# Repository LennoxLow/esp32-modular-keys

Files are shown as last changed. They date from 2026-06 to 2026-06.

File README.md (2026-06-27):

# ESP32 MODULAR HOTKEY SYSTEM 🔘✨
*"A physical button that can trigger anything. The first thing I used it for was generating meme compilations."*

---

## 🎬 As Seen In
This project appeared in my YouTube video:
I automated making meme compilations so I never have to watch Reddit again (https://www.youtube.com/watch?v=LXZIZYsod2A) 

And yes — it's also on Instructables 👀
[[Happy Modular HotKeys](https://www.instructables.com/Happy-Modular-HotKeys-ESP32/)]

---

## ⚠️ What Is This?

Running a script from a terminal works fine.

But I wanted a physical button. Something that felt like I was actually doing something rather than typing `python main.py` and pressing enter like some kind of person who uses a computer normally.

So I built one. And then it got a bit out of hand.

Each module is an ESP32 with a button, an OLED display, and a 20-frame animation that plays when a trigger fires. The interesting part is what happens when you connect more than one — they negotiate master and slave roles automatically with no configuration, communicate over a serial bus, and broadcast triggers over WiFi UDP so everything connected hears every press.

Press any button on any module. Everything reacts.

---

## 🧠 Features

- Auto master/slave role negotiation via shared flag pin — no configuration needed
- Serial bus communication between modules (daisy-chainable)
- WiFi UDP broadcast so triggers reach anything on the network
- Automatic master promotion if master module is powered off
- GUID-based device identity — every module knows who sent what
- 20-frame OLED animation stored in PROGMEM — no SD card needed
- 25ms debounce on button input
- Periodic slave keepalive announcements
- Serial listener on PC side triggers any script on button press
- Modular — add as many buttons as you want

---

## 🧰 Parts List

| Part | Notes |
|---|---|
| ESP32 (any variant) | One per module |
| Tactile push button | Wired to GPIO6 and GND |
| 0.66 Inch OLED  | I²C, address 0x3C |
| Jumper wires | For the bus between modules |
| USB cable | Flashing and power |
| 3D printed enclosure | Optional but satisfying |
| Arduino IDE | Where bugs are born |

---

## 🗺️ GPIO Map

| Pin | Function |
|-----|---|
| GPIO 4 | I²C SDA → OLED |
| GPIO 5 | I²C SCL → OLED |
| GPIO 6 | Button (INPUT_PULLUP — wire to GND) |
| GPIO 7 | Master/slave flag pin |
| GPIO 20 | Serial RX (swapped on slave) |
| GPIO 21 | Serial TX (swapped on slave) |

**Button wiring:** One leg to GPIO6, other leg to GND. The internal pullup holds the pin HIGH. Press pulls it LOW — that's your trigger.

**Flag pin wiring:** Connect GPIO7 on all modules together with a single shared wire. This is how they negotiate roles on boot.

**Serial bus wiring:** TX of one module to RX of the next. Daisy chain as many as you want.

---

## 🧠 How the Master/Slave Negotiation Works

On boot, every module checks the shared flag pin (GPIO7):

- **Pin is LOW** — nobody has claimed master yet. This module sets the pin HIGH, declares itself master, and connects to WiFi.
- **Pin is HIGH** — a master already exists. This module becomes a slave, announces itself over the serial bus, and waits.

Power off the master mid-session — the slave detects the flag pin going LOW, waits 2 seconds to confirm it's not a glitch, then promotes itself to master.

No configuration. No pre-assignment. They just figure it out.

---

## 📡 Trigger Flow

**Master button pressed:**
```
Master button → broadcastMessage() → WiFi UDP + Serial bus → all modules react
```

**Slave button pressed:**
```
Slave button → busSend() to master → master forwards via broadcastMessage() → all modules react
```

Every trigger message includes the sending module's GUID so you always know which button fired.

---

## 🖥️ PC Serial Listener

A Python script on the PC side watches the serial port. When it receives a `TRIGGER` message from the master module it fires whatever script you point it at.

```python
import serial
import subprocess

ser = serial.Serial('COM3', 115200)  # Change to your port

while True:
    if ser.in_waiting:
        line = ser.readline().decode('utf-8').strip()
        if 'TRIGGER' in line:
            subprocess.call(['python', 'main.py'])
```

Change `COM3` to your actual port. Change `main.py` to whatever you want the button to run. That's the entire bridge between hardware and software.

---

## 🚀 Setup

**1. Install Arduino IDE**

Download from arduino.cc.

**2. Add ESP32 board support**

In Arduino IDE preferences, add this to Additional Board Manager URLs:
```
https://raw.githubusercontent.com/espressif/arduino-esp32/gh-pages/package_esp32_index.json
```

Then install `esp32` via Board Manager.

**3. Install libraries**

In Library Manager, install:
- `Adafruit SSD1306`
- `Adafruit GFX`

**4. Configure WiFi credentials**

In the firmware, find and update:
```cpp
const char* ssid = "YOUR_WIFI_SSID";
const char* password = "YOUR_WIFI_PASSWORD";
```

**5. Flash each module**

- Connect via USB
- Select your ESP32 board
- Upload the sketch
- Repeat for each module

**6. Wire the modules together**

- Connect all GPIO7 pins together (flag bus)
- Connect TX/RX in daisy chain for serial bus
- Power all modules

**7. Run the serial listener**

```bash
python listener.py
```

**8. Press the button**

---

## ✨ The OLED Animation

When any trigger fires, all connected OLED screens play a 20-frame bounce animation.

The animation frames are stored as raw bitmaps in PROGMEM — meaning they live in flash memory on the microcontroller itself. No SD card, no external storage, no loading time. It just plays.

Each frame is 46×46 pixels. The animation plays forward then reverses in a loop until the next trigger.

---

## 🛠️ Troubleshooting

**OLED is blank**
- Check I²C wiring — SDA to GPIO4, SCL to GPIO5
- Confirm I²C address is `0x3C`
- Check common ground between ESP32 and OLED

**Modules not negotiating roles correctly**
- Make sure GPIO7 is connected between all modules with a shared wire
- Check that GPIO7 is not connected to anything else
- Power modules on one at a time to observe negotiation

**Slave not receiving triggers from master**
- Check TX/RX wiring — master TX to slave TX pin (firmware swaps it internally)
- Confirm both modules share a common ground
- Check baud rate is 115200 on both

**WiFi not connecting**
- Check SSID and password in firmware
- Master only connects to WiFi — slaves use serial bus only
- If WiFi fails, the master falls back to serial bus automatically

**Serial listener not receiving triggers**
- Check COM port — use Device Manager on Windows to find it
- Confirm baud rate is 115200
- Make sure the master module is connected to the PC, not a slave

**Button not triggering**
- Check wiring: one leg to GPIO6, other leg to GND
- Confirm `INPUT_PULLUP` is set in firmware
- Trigger fires on LOW — pressing should pull the pin to GND

---

## 🚀 Future Shenanigans

- Different trigger types per button (long press, double press)
- Battery power + wireless only mode
- Per-module custom animations
- Web interface for trigger configuration
- More modules obviously

---

## 🔗 Companion Project

The button was built to trigger this:
👉 [LennoxLow/Automatic-Meme-Compilation-Creator]((https://github.com/LennoxLow/Automatic-Meme-Compilation-Creator))

But it can trigger anything that runs from a command line.

I haven't decided what to make it do next.

---

## 🖤 License

Do whatever.
Attribute me if you feel polite.

-readme was generated, instructables is a good source for any additional information-

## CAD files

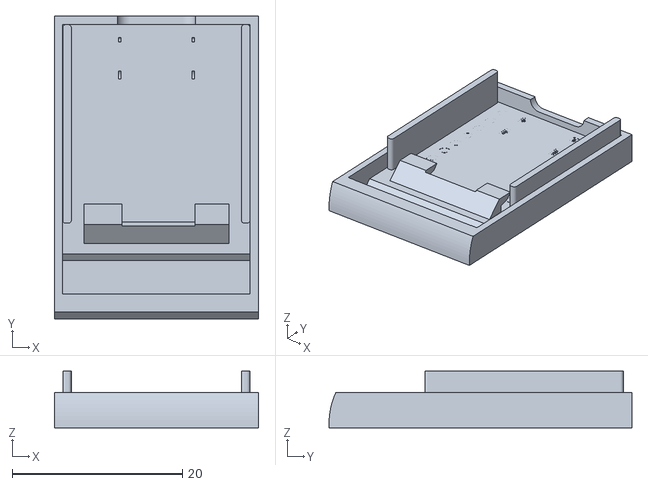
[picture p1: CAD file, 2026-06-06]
Quickkeys- bottom.stl
24.0 x 35.6 x 6.66

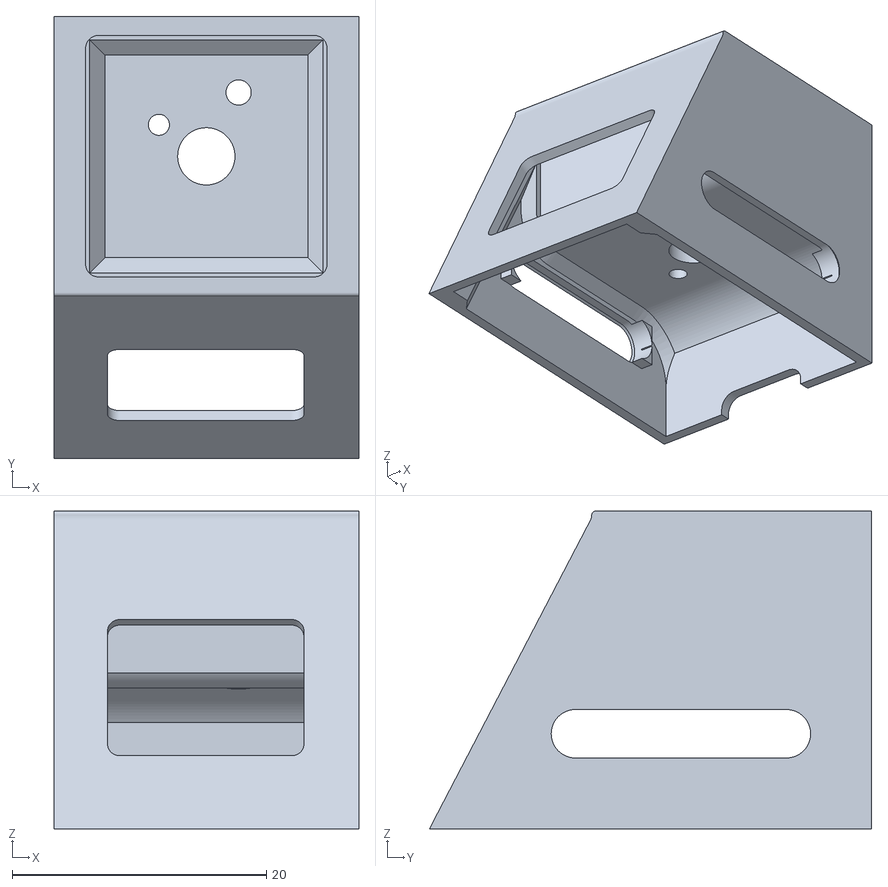
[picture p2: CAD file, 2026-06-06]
Quickkeys-newtop.stl
24.0 x 34.8 x 25.0

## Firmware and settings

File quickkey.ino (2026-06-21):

#include <Wire.h>
#include <Adafruit_GFX.h>
#include <Adafruit_SSD1306.h>
#include <WiFi.h>
#include <WiFiUdp.h>
#include <Preferences.h>

// === Wi-Fi config ===
const char* ssid = "YOUR_WIFI_SSID";
const char* password = "YOUR_WIFI_PASSWORD";
const int udpPort = 5555;
WiFiUDP udp;
IPAddress broadcastIP;
bool wifiActive = false;

// === Screen config ===
#define SCREEN_WIDTH 128
#define SCREEN_HEIGHT 64
#define OLED_ADDR 0x3C
Adafruit_SSD1306 display(SCREEN_WIDTH, SCREEN_HEIGHT, &Wire, -1);

// === Pins ===
#define PIN_BUTTON 6
#define PIN_FLAG   7
#define PIN_SDA    4
#define PIN_SCL    5
#define PIN_RX     20
#define PIN_TX     21

// === Debounce ===
unsigned long lastDebounceTime = 0;
unsigned long debounceDelay = 25;
bool buttonState = HIGH;
bool lastButtonReading = HIGH;

// === Bus Communication ===
#define BAUD 115200
bool isMaster = false;
String guid;
String unitName;
Preferences prefs;
unsigned long lastSlaveAnnounce = 0;
unsigned long slaveAnnounceInterval = 5000;

// === Animation state machine ===
enum AnimState { IDLE, TRIGGERED, COMBO };
AnimState animState = IDLE;
unsigned long lastFrameTime = 0;
unsigned long stateStartTime = 0;
int currentFrame = 0;
bool animationReverse = false;
String overlayText = "";
const int IDLE_FRAME_DELAY      = 120;
const int TRIGGERED_FRAME_DELAY = 55;
const int COMBO_FRAME_DELAY     = 35;
const unsigned long TRIGGERED_DURATION = 1500;
const unsigned long COMBO_DURATION     = 2500;

// === Long press ===
unsigned long buttonPressedAt = 0;
bool longPressFired = false;
const unsigned long LONG_PRESS_MS = 800;

// === Slave tracking (master only) ===
#define MAX_SLAVES 8
struct SlaveInfo { String guid; String name; unsigned long lastSeen; };
SlaveInfo slaves[MAX_SLAVES];
int slaveCount = 0;
const unsigned long SLAVE_TIMEOUT = 15000;

// === Combo detection (master only) ===
#define MAX_COMBO_TRACK 8
struct RecentTrigger { String name; unsigned long time; };
RecentTrigger recentTriggers[MAX_COMBO_TRACK];
int recentTriggerCount = 0;
const unsigned long COMBO_WINDOW_MS = 600;

// === Sprite frames (45x45px) ===
// ========================================
// ANIMATION FRAMES - Dance (46x46px, 20 frames)
// ========================================
// 'frame_00_delay-0', 46x46px
const unsigned char frame_00 [] PROGMEM = {
	0x00, 0x00, 0x00, 0x00, 0x00, 0x00, 0x00, 0x00, 0x00, 0x00, 0x00, 0x00, 0x00, 0x00, 0x00, 0x00, 
	0x00, 0x00, 0x00, 0x00, 0x00, 0x00, 0x00, 0x00, 0x00, 0x00, 0x00, 0x00, 0x00, 0x00, 0x00, 0x00, 
	0x07, 0xfc, 0x00, 0x00, 0x00, 0x00, 0x3f, 0xff, 0x80, 0x00, 0x00, 0x01, 0xff, 0xff, 0xe0, 0x00, 
	0x00, 0x07, 0xff, 0xff, 0xf8, 0x00, 0x00, 0x0f, 0xff, 0xff, 0xfc, 0x00, 0x00, 0x1f, 0xff, 0xff, 
	0xfe, 0x00, 0x00, 0x3f, 0xff, 0xff, 0xff, 0x00, 0x00, 0x7f, 0xff, 0xff, 0x0f, 0x00, 0x00, 0xff, 
	0xff, 0xfe, 0x0f, 0x80, 0x01, 0xff, 0xe3, 0xfe, 0x07, 0x80, 0x01, 0xff, 0xe1, 0xff, 0x07, 0xc0, 
	0x03, 0xff, 0xc0, 0xff, 0x07, 0xc0, 0x03, 0xff, 0xc0, 0xff, 0xdf, 0xe0, 0x07, 0xff, 0xe0, 0xff, 
	0xff, 0xe0, 0x07, 0xff, 0xe1, 0xff, 0xff, 0xe0, 0x0f, 0xff, 0xff, 0xff, 0xe7, 0xe0, 0x0f, 0xff, 
	0xff, 0xff, 0x87, 0xf0, 0x0f, 0xff, 0xfd, 0xfe, 0x1f, 0xf0, 0x1f, 0xff, 0xfc, 0x00, 0x7f, 0xf0, 
	0x1f, 0xff, 0xfe, 0x01, 0xff, 0xf0, 0x1f, 0xff, 0xff, 0xff, 0xff, 0xf0, 0x3f, 0xff, 0xff, 0xff, 
	0xff, 0xf0, 0x3f, 0xff, 0xff, 0xff, 0xff, 0xf0, 0x3f, 0xff, 0xff, 0xff, 0xff, 0xf0, 0x3f, 0xff, 
	0xff, 0xff, 0xff, 0xf0, 0x3f, 0xff, 0xff, 0xff, 0xff, 0xf0, 0x3f, 0xff, 0xff, 0xff, 0xff, 0xf0, 
	0x3f, 0xff, 0xff, 0xff, 0xff, 0xf0, 0x3f, 0xff, 0xff, 0xff, 0xff, 0xf0, 0x3f, 0xff, 0xff, 0xff, 
	0xff, 0xf0, 0x1f, 0xff, 0xff, 0xff, 0xff, 0xe0, 0x0f, 0xff, 0xff, 0xff, 0xff, 0xc0, 0x03, 0xff, 
	0xff, 0xff, 0xff, 0x00, 0x01, 0xff, 0xff, 0xff, 0xfe, 0x00, 0x00, 0x1f, 0xff, 0xff, 0xe0, 0x00, 
	0x00, 0x01, 0xff, 0xfe, 0x00, 0x00, 0x00, 0x00, 0x00, 0x00, 0x00, 0x00, 0x00, 0x00, 0x00, 0x00, 
	0x00, 0x00, 0x00, 0x00, 0x00, 0x00, 0x00, 0x00, 0x00, 0x00, 0x00, 0x00, 0x00, 0x00, 0x00, 0x00, 
	0x00, 0x00, 0x00, 0x00
};
// 'frame_01_delay-0', 46x46px
const unsigned char frame_01 [] PROGMEM = {
	0x00, 0x00, 0x00, 0x00, 0x00, 0x00, 0x00, 0x00, 0x00, 0x00, 0x00, 0x00, 0x00, 0x00, 0x00, 0x00, 
	0x00, 0x00, 0x00, 0x00, 0x00, 0x00, 0x00, 0x00, 0x00, 0x00, 0x00, 0x00, 0x00, 0x00, 0x00, 0x00, 
	0x3f, 0xf0, 0x00, 0x00, 0x00, 0x01, 0xff, 0xfe, 0x00, 0x00, 0x00, 0x0f, 0xff, 0xff, 0xc0, 0x00, 
	0x00, 0x1f, 0xff, 0xff, 0xe0, 0x00, 0x00, 0x3f, 0xff, 0xff, 0xf0, 0x00, 0x00, 0x7f, 0xff, 0xff, 
	0xf8, 0x00, 0x00, 0xff, 0xff, 0xff, 0xfc, 0x00, 0x01, 0xff, 0xff, 0xff, 0xfe, 0x00, 0x01, 0xff, 
	0xff, 0xfc, 0x7e, 0x00, 0x03, 0xff, 0xff, 0xf8, 0x3f, 0x00, 0x07, 0xff, 0xcf, 0xf8, 0x1f, 0x80, 
	0x07, 0xff, 0x87, 0xf8, 0x1f, 0x80, 0x07, 0xff, 0x07, 0xfc, 0x1f, 0xc0, 0x0f, 0xff, 0x03, 0xfc, 
	0x3f, 0xc0, 0x0f, 0xff, 0x03, 0xff, 0xff, 0xc0, 0x0f, 0xff, 0x87, 0xff, 0xff, 0xc0, 0x1f, 0xff, 
	0xcf, 0xff, 0xff, 0xe0, 0x1f, 0xff, 0xff, 0xff, 0x1f, 0xe0, 0x1f, 0xff, 0xff, 0xfc, 0x3f, 0xe0, 
	0x3f, 0xff, 0xe0, 0x00, 0xff, 0xf0, 0x3f, 0xff, 0xf0, 0x07, 0xff, 0xf0, 0x3f, 0xff, 0xff, 0xff, 
	0xff, 0xf0, 0x3f, 0xff, 0xff, 0xff, 0xff, 0xf0, 0x3f, 0xff, 0xff, 0xff, 0xff, 0xf0, 0x3f, 0xff, 
	0xff, 0xff, 0xff, 0xf0, 0x3f, 0xff, 0xff, 0xff, 0xff, 0xf0, 0x3f, 0xff, 0xff, 0xff, 0xff, 0xf0, 
	0x3f, 0xff, 0xff, 0xff, 0xff, 0xf0, 0x3f, 0xff, 0xff, 0xff, 0xff, 0xf0, 0x3f, 0xff, 0xff, 0xff, 
	0xff, 0xf0, 0x1f, 0xff, 0xff, 0xff, 0xff, 0xe0, 0x0f, 0xff, 0xff, 0xff, 0xff, 0xc0, 0x03, 0xff, 
	0xff, 0xff, 0xff, 0x00, 0x01, 0xff, 0xff, 0xff, 0xfe, 0x00, 0x00, 0x1f, 0xff, 0xff, 0xe0, 0x00, 
	0x00, 0x01, 0xff, 0xfe, 0x00, 0x00, 0x00, 0x00, 0x00, 0x00, 0x00, 0x00, 0x00, 0x00, 0x00, 0x00, 
	0x00, 0x00, 0x00, 0x00, 0x00, 0x00, 0x00, 0x00, 0x00, 0x00, 0x00, 0x00, 0x00, 0x00, 0x00, 0x00, 
	0x00, 0x00, 0x00, 0x00
};
// 'frame_02_delay-0', 46x46px
const unsigned char frame_02 [] PROGMEM = {
	0x00, 0x00, 0x00, 0x00, 0x00, 0x00, 0x00, 0x00, 0x00, 0x00, 0x00, 0x00, 0x00, 0x00, 0x00, 0x00, 
	0x00, 0x00, 0x00, 0x00, 0x00, 0x00, 0x00, 0x00, 0x00, 0x00, 0x00, 0x00, 0x00, 0x00, 0x00, 0x00, 
	0x7f, 0xc0, 0x00, 0x00, 0x00, 0x03, 0xff, 0xf8, 0x00, 0x00, 0x00, 0x0f, 0xff, 0xff, 0x00, 0x00, 
	0x00, 0x3f, 0xff, 0xff, 0xc0, 0x00, 0x00, 0x7f, 0xff, 0xff, 0xe0, 0x00, 0x00, 0xff, 0xff, 0xff, 
	0xf0, 0x00, 0x01, 0xff, 0xff, 0xff, 0xf8, 0x00, 0x01, 0xfe, 0x7f, 0xf3, 0xfc, 0x00, 0x03, 0xfc, 
	0x3f, 0xe1, 0xfc, 0x00, 0x03, 0xfc, 0x1f, 0xe1, 0xfe, 0x00, 0x07, 0xf8, 0x1f, 0xc0, 0xff, 0x00, 
	0x07, 0xfc, 0x1f, 0xe1, 0xff, 0x00, 0x0f, 0xfc, 0x3f, 0xe1, 0xff, 0x80, 0x0f, 0xfe, 0x7f, 0xff, 
	0xff, 0x80, 0x0f, 0xff, 0xff, 0xff, 0xff, 0xc0, 0x1f, 0xff, 0xff, 0xff, 0xff, 0xc0, 0x1f, 0xfe, 
	0x7f, 0xfb, 0xff, 0xc0, 0x1f, 0xfe, 0x0f, 0x83, 0xff, 0xe0, 0x1f, 0xff, 0x80, 0x0f, 0xff, 0xe0, 
	0x3f, 0xff, 0xf0, 0x7f, 0xff, 0xe0, 0x3f, 0xff, 0xff, 0xff, 0xff, 0xe0, 0x3f, 0xff, 0xff, 0xff, 
	0xff, 0xf0, 0x3f, 0xff, 0xff, 0xff, 0xff, 0xf0, 0x3f, 0xff, 0xff, 0xff, 0xff, 0xf0, 0x3f, 0xff, 
	0xff, 0xff, 0xff, 0xf0, 0x3f, 0xff, 0xff, 0xff, 0xff, 0xf0, 0x3f, 0xff, 0xff, 0xff, 0xff, 0xf0, 
	0x3f, 0xff, 0xff, 0xff, 0xff, 0xf0, 0x3f, 0xff, 0xff, 0xff, 0xff, 0xf0, 0x3f, 0xff, 0xff, 0xff, 
	0xff, 0xf0, 0x1f, 0xff, 0xff, 0xff, 0xff, 0xe0, 0x0f, 0xff, 0xff, 0xff, 0xff, 0xc0, 0x03, 0xff, 
	0xff, 0xff, 0xff, 0x00, 0x01, 0xff, 0xff, 0xff, 0xfe, 0x00, 0x00, 0x1f, 0xff, 0xff, 0xe0, 0x00, 
	0x00, 0x01, 0xff, 0xfe, 0x00, 0x00, 0x00, 0x00, 0x00, 0x00, 0x00, 0x00, 0x00, 0x00, 0x00, 0x00, 
	0x00, 0x00, 0x00, 0x00, 0x00, 0x00, 0x00, 0x00, 0x00, 0x00, 0x00, 0x00, 0x00, 0x00, 0x00, 0x00, 
	0x00, 0x00, 0x00, 0x00
};
// 'frame_03_delay-0', 46x46px
const unsigned char frame_03 [] PROGMEM = {
	0x00, 0x00, 0x00, 0x00, 0x00, 0x00, 0x00, 0x00, 0x00, 0x00, 0x00, 0x00, 0x00, 0x00, 0x00, 0x00, 
	0x00, 0x00, 0x00, 0x00, 0x00, 0x00, 0x00, 0x00, 0x00, 0x00, 0x00, 0x00, 0x00, 0x00, 0x00, 0x00, 
	0x00, 0x00, 0x00, 0x00, 0x00, 0x00, 0x7f, 0x80, 0x00, 0x00, 0x00, 0x0f, 0xff, 0xf8, 0x00, 0x00, 
	0x00, 0x3f, 0xff, 0xfe, 0x00, 0x00, 0x00, 0x7f, 0xff, 0xff, 0x80, 0x00, 0x00, 0xff, 0xff, 0xff, 
	0xc0, 0x00, 0x01, 0xff, 0xff, 0xff, 0xe0, 0x00, 0x03, 0xff, 0xff, 0xcf, 0xf0, 0x00, 0x07, 0xff, 
	0xff, 0x83, 0xf8, 0x00, 0x07, 0xf9, 0xff, 0x83, 0xfc, 0x00, 0x0f, 0xf0, 0x7f, 0x83, 0xfe, 0x00, 
	0x0f, 0xf0, 0x7f, 0x83, 0xfe, 0x00, 0x0f, 0xf0, 0x7f, 0xc7, 0xff, 0x00, 0x1f, 0xf0, 0x7f, 0xff, 
	0xff, 0x80, 0x1f, 0xf0, 0x7f, 0xff, 0xff, 0x80, 0x1f, 0xfd, 0xff, 0xff, 0xff, 0xc0, 0x3f, 0xff, 
	0xff, 0xe3, 0xff, 0xc0, 0x3f, 0xff, 0xff, 0x87, 0xff, 0xc0, 0x3f, 0xfe, 0x00, 0x1f, 0xff, 0xe0, 
	0x3f, 0xff, 0x00, 0x7f, 0xff, 0xe0, 0x3f, 0xff, 0xff, 0xff, 0xff, 0xe0, 0x3f, 0xff, 0xff, 0xff, 
	0xff, 0xf0, 0x3f, 0xff, 0xff, 0xff, 0xff, 0xf0, 0x3f, 0xff, 0xff, 0xff, 0xff, 0xf0, 0x3f, 0xff, 
	0xff, 0xff, 0xff, 0xf0, 0x3f, 0xff, 0xff, 0xff, 0xff, 0xf0, 0x3f, 0xff, 0xff, 0xff, 0xff, 0xf0, 
	0x3f, 0xff, 0xff, 0xff, 0xff, 0xf0, 0x3f, 0xff, 0xff, 0xff, 0xff, 0xf0, 0x3f, 0xff, 0xff, 0xff, 
	0xff, 0xf0, 0x1f, 0xff, 0xff, 0xff, 0xff, 0xe0, 0x0f, 0xff, 0xff, 0xff, 0xff, 0xc0, 0x03, 0xff, 
	0xff, 0xff, 0xff, 0x00, 0x01, 0xff, 0xff, 0xff, 0xfe, 0x00, 0x00, 0x1f, 0xff, 0xff, 0xe0, 0x00, 
	0x00, 0x01, 0xff, 0xfe, 0x00, 0x00, 0x00, 0x00, 0x00, 0x00, 0x00, 0x00, 0x00, 0x00, 0x00, 0x00, 
	0x00, 0x00, 0x00, 0x00, 0x00, 0x00, 0x00, 0x00, 0x00, 0x00, 0x00, 0x00, 0x00, 0x00, 0x00, 0x00, 
	0x00, 0x00, 0x00, 0x00
};
// 'frame_04_delay-0', 46x46px
const unsigned char frame_04 [] PROGMEM = {
	0x00, 0x00, 0x00, 0x00, 0x00, 0x00, 0x00, 0x00, 0x00, 0x00, 0x00, 0x00, 0x00, 0x00, 0x00, 0x00, 
	0x00, 0x00, 0x00, 0x00, 0x00, 0x00, 0x00, 0x00, 0x00, 0x00, 0x00, 0x00, 0x00, 0x00, 0x00, 0x00, 
	0x00, 0x00, 0x00, 0x00, 0x00, 0x07, 0xff, 0x00, 0x00, 0x00, 0x00, 0x3f, 0xff, 0xf0, 0x00, 0x00, 
	0x00, 0x7f, 0xff, 0xfc, 0x00, 0x00, 0x01, 0xff, 0xff, 0xff, 0x00, 0x00, 0x03, 0xff, 0xff, 0xff, 
	0x80, 0x00, 0x07, 0xff, 0xff, 0xff, 0xc0, 0x00, 0x07, 0xff, 0xff, 0xff, 0xe0, 0x00, 0x0f, 0xff, 
	0xfc, 0x7f, 0xf0, 0x00, 0x0f, 0xdf, 0xf8, 0x3f, 0xf8, 0x00, 0x1f, 0x87, 0xf8, 0x1f, 0xfc, 0x00, 
	0x1f, 0x07, 0xf8, 0x1f, 0xfe, 0x00, 0x3f, 0x03, 0xfc, 0x1f, 0xfe, 0x00, 0x3f, 0x03, 0xfe, 0x3f, 
	0xff, 0x00, 0x3f, 0x87, 0xff, 0xff, 0xff, 0x00, 0x3f, 0xcf, 0xff, 0xff, 0xff, 0x80, 0x3f, 0xff, 
	0xff, 0xff, 0xff, 0x80, 0x3f, 0xff, 0xfe, 0x3f, 0xff, 0xc0, 0x3f, 0xe3, 0xf0, 0x7f, 0xff, 0xc0, 
	0x7f, 0xe0, 0x01, 0xff, 0xff, 0xc0, 0x7f, 0xfe, 0x1f, 0xff, 0xff, 0xe0, 0x7f, 0xff, 0xff, 0xff, 
	0xff, 0xe0, 0x3f, 0xff, 0xff, 0xff, 0xff, 0xe0, 0x7f, 0xff, 0xff, 0xff, 0xff, 0xf0, 0x3f, 0xff, 
	0xff, 0xff, 0xff, 0xf0, 0x3f, 0xff, 0xff, 0xff, 0xff, 0xf0, 0x3f, 0xff, 0xff, 0xff, 0xff, 0xf0, 
	0x3f, 0xff, 0xff, 0xff, 0xff, 0xf0, 0x3f, 0xff, 0xff, 0xff, 0xff, 0xf0, 0x3f, 0xff, 0xff, 0xff, 
	0xff, 0xf0, 0x1f, 0xff, 0xff, 0xff, 0xff, 0xe0, 0x0f, 0xff, 0xff, 0xff, 0xff, 0xc0, 0x03, 0xff, 
	0xff, 0xff, 0xff, 0x80, 0x01, 0xff, 0xff, 0xff, 0xfe, 0x00, 0x00, 0x1f, 0xff, 0xff, 0xe0, 0x00, 
	0x00, 0x01, 0xff, 0xfe, 0x00, 0x00, 0x00, 0x00, 0x00, 0x00, 0x00, 0x00, 0x00, 0x00, 0x00, 0x00, 
	0x00, 0x00, 0x00, 0x00, 0x00, 0x00, 0x00, 0x00, 0x00, 0x00, 0x00, 0x00, 0x00, 0x00, 0x00, 0x00, 
	0x00, 0x00, 0x00, 0x00
};
// 'frame_05_delay-0', 46x46px
const unsigned char frame_05 [] PROGMEM = {
	0x00, 0x00, 0x00, 0x00, 0x00, 0x00, 0x00, 0x00, 0x00, 0x00, 0x00, 0x00, 0x00, 0x00, 0x00, 0x00, 
	0x00, 0x00, 0x00, 0x00, 0x00, 0x00, 0x00, 0x00, 0x00, 0x00, 0x00, 0x00, 0x00, 0x00, 0x00, 0x00, 
	0x00, 0x00, 0x00, 0x00, 0x00, 0x0f, 0xff, 0xc0, 0x00, 0x00, 0x00, 0x7f, 0xff, 0xf8, 0x00, 0x00, 
	0x00, 0xff, 0xff, 0xfc, 0x00, 0x00, 0x01, 0xff, 0xff, 0xff, 0x00, 0x00, 0x03, 0xff, 0xff, 0xff, 
	0x80, 0x00, 0x07, 0xff, 0xff, 0xff, 0xe0, 0x00, 0x0f, 0xff, 0xff, 0xff, 0xf0, 0x00, 0x0f, 0xff, 
	0xff, 0xff, 0xf0, 0x00, 0x0f, 0xff, 0xff, 0xff, 0xf8, 0x00, 0x1f, 0xff, 0xff, 0xff, 0xfc, 0x00, 
	0x1e, 0x3f, 0xe1, 0xff, 0xfe, 0x00, 0x3c, 0x3f, 0xe0, 0xff, 0xfe, 0x00, 0x3c, 0x1f, 0xe0, 0xff, 
	0xff, 0x00, 0x3c, 0x1f, 0xe0, 0xff, 0xff, 0x00, 0x3c, 0x1f, 0xe0, 0xff, 0xff, 0x80, 0x3c, 0x3f, 
	0xfb, 0xff, 0xff, 0x80, 0x3f, 0xff, 0xff, 0xff, 0xff, 0xc0, 0x3f, 0xff, 0xff, 0xff, 0xff, 0xc0, 
	0x3f, 0xff, 0xf9, 0xff, 0xff, 0xc0, 0x7f, 0x1f, 0xe1, 0xff, 0xff, 0xe0, 0x7f, 0x80, 0x03, 0xff, 
	0xff, 0xe0, 0x7f, 0xf0, 0x3f, 0xff, 0xff, 0xf0, 0x7f, 0xff, 0xff, 0xff, 0xff, 0xf0, 0x3f, 0xff, 
	0xff, 0xff, 0xff, 0xf0, 0x3f, 0xff, 0xff, 0xff, 0xff, 0xf0, 0x3f, 0xff, 0xff, 0xff, 0xff, 0xf0, 
	0x3f, 0xff, 0xff, 0xff, 0xff, 0xf0, 0x3f, 0xff, 0xff, 0xff, 0xff, 0xf0, 0x3f, 0xff, 0xff, 0xff, 
	0xff, 0xf0, 0x1f, 0xff, 0xff, 0xff, 0xff, 0xe0, 0x0f, 0xff, 0xff, 0xff, 0xff, 0xc0, 0x03, 0xff, 
	0xff, 0xff, 0xff, 0x80, 0x01, 0xff, 0xff, 0xff, 0xfe, 0x00, 0x00, 0x1f, 0xff, 0xff, 0xe0, 0x00, 
	0x00, 0x01, 0xff, 0xfe, 0x00, 0x00, 0x00, 0x00, 0x00, 0x00, 0x00, 0x00, 0x00, 0x00, 0x00, 0x00, 
	0x00, 0x00, 0x00, 0x00, 0x00, 0x00, 0x00, 0x00, 0x00, 0x00, 0x00, 0x00, 0x00, 0x00, 0x00, 0x00, 
	0x00, 0x00, 0x00, 0x00
};
// 'frame_06_delay-0', 46x46px
const unsigned char frame_06 [] PROGMEM = {
	0x00, 0x00, 0x00, 0x00, 0x00, 0x00, 0x00, 0x00, 0x00, 0x00, 0x00, 0x00, 0x00, 0x00, 0x00, 0x00, 
	0x00, 0x00, 0x00, 0x00, 0x00, 0x00, 0x00, 0x00, 0x00, 0x00, 0x00, 0x00, 0x00, 0x00, 0x00, 0x00, 
	0x00, 0x00, 0x00, 0x00, 0x00, 0x00, 0x00, 0x00, 0x00, 0x00, 0x00, 0x00, 0xe0, 0x00, 0x00, 0x00, 
	0x00, 0x1f, 0xff, 0x00, 0x00, 0x00, 0x00, 0xff, 0xff, 0xf0, 0x00, 0x00, 0x01, 0xff, 0xff, 0xfc, 
	0x00, 0x00, 0x03, 0xff, 0xff, 0xff, 0x00, 0x00, 0x07, 0xff, 0xff, 0xff, 0x80, 0x00, 0x0f, 0xff, 
	0xff, 0xff, 0xc0, 0x00, 0x1f, 0xff, 0xff, 0xff, 0xe0, 0x00, 0x1f, 0xff, 0xff, 0xff, 0xf0, 0x00, 
	0x3f, 0xff, 0xff, 0xff, 0xf8, 0x00, 0x3f, 0x9f, 0xfd, 0xff, 0xfc, 0x00, 0x3e, 0x0f, 0xf8, 0x7f, 
	0xfe, 0x00, 0x3e, 0x0f, 0xf0, 0x7f, 0xfe, 0x00, 0x3e, 0x0f, 0xf0, 0x7f, 0xff, 0x00, 0x7e, 0x0f, 
	0xf0, 0x7f, 0xff, 0x80, 0x7f, 0x0f, 0xf8, 0x7f, 0xff, 0x80, 0x7f, 0xbf, 0xff, 0xff, 0xff, 0xc0, 
	0x7f, 0xff, 0xff, 0xff, 0xff, 0xc0, 0x7f, 0xff, 0xff, 0xff, 0xff, 0xc0, 0x7f, 0x9f, 0xfe, 0xff, 
	0xff, 0xe0, 0x7f, 0xc0, 0x00, 0xff, 0xff, 0xe0, 0x7f, 0xe0, 0x03, 0xff, 0xff, 0xf0, 0x7f, 0xff, 
	0xff, 0xff, 0xff, 0xf0, 0x3f, 0xff, 0xff, 0xff, 0xff, 0xf0, 0x3f, 0xff, 0xff, 0xff, 0xff, 0xf0, 
	0x3f, 0xff, 0xff, 0xff, 0xff, 0xf0, 0x3f, 0xff, 0xff, 0xff, 0xff, 0xf0, 0x3f, 0xff, 0xff, 0xff, 
	0xff, 0xf0, 0x1f, 0xff, 0xff, 0xff, 0xff, 0xe0, 0x0f, 0xff, 0xff, 0xff, 0xff, 0xc0, 0x03, 0xff, 
	0xff, 0xff, 0xff, 0x80, 0x01, 0xff, 0xff, 0xff, 0xfe, 0x00, 0x00, 0x1f, 0xff, 0xff, 0xe0, 0x00, 
	0x00, 0x01, 0xff, 0xfe, 0x00, 0x00, 0x00, 0x00, 0x00, 0x00, 0x00, 0x00, 0x00, 0x00, 0x00, 0x00, 
	0x00, 0x00, 0x00, 0x00, 0x00, 0x00, 0x00, 0x00, 0x00, 0x00, 0x00, 0x00, 0x00, 0x00, 0x00, 0x00, 
	0x00, 0x00, 0x00, 0x00
};
// 'frame_07_delay-0', 46x46px
const unsigned char frame_07 [] PROGMEM = {
	0x00, 0x00, 0x00, 0x00, 0x00, 0x00, 0x00, 0x00, 0x00, 0x00, 0x00, 0x00, 0x00, 0x00, 0x00, 0x00, 
	0x00, 0x00, 0x00, 0x00, 0x00, 0x00, 0x00, 0x00, 0x00, 0x00, 0x00, 0x00, 0x00, 0x00, 0x00, 0x00, 
	0x00, 0x00, 0x00, 0x00, 0x00, 0x00, 0x00, 0x00, 0x00, 0x00, 0x00, 0x00, 0x00, 0x00, 0x00, 0x00, 
	0x00, 0x00, 0x00, 0x00, 0x00, 0x00, 0x00, 0x1f, 0xfc, 0x00, 0x00, 0x00, 0x00, 0xff, 0xff, 0xc0, 
	0x00, 0x00, 0x03, 0xff, 0xff, 0xf0, 0x00, 0x00, 0x0f, 0xff, 0xff, 0xfc, 0x00, 0x00, 0x0f, 0xff, 
	0xff, 0xff, 0x00, 0x00, 0x1f, 0xff, 0xff, 0xff, 0x80, 0x00, 0x3f, 0xff, 0xff, 0xff, 0xc0, 0x00, 
	0x3f, 0xff, 0xff, 0xff, 0xe0, 0x00, 0x3f, 0xff, 0xff, 0xff, 0xf0, 0x00, 0x7f, 0xff, 0xff, 0xff, 
	0xf8, 0x00, 0x7f, 0x87, 0xfe, 0x7f, 0xfc, 0x00, 0x7f, 0x07, 0xfc, 0x3f, 0xfe, 0x00, 0x7f, 0x03, 
	0xf8, 0x3f, 0xff, 0x00, 0x7f, 0x07, 0xf8, 0x1f, 0xff, 0x00, 0x7f, 0x87, 0xfc, 0x1f, 0xff, 0x80, 
	0x7f, 0x8f, 0xfc, 0x3f, 0xff, 0xc0, 0x7f, 0xff, 0xff, 0x7f, 0xff, 0xc0, 0x7f, 0xff, 0xff, 0xff, 
	0xff, 0xc0, 0x7f, 0xcf, 0xff, 0xff, 0xff, 0xe0, 0x7f, 0xc3, 0xfe, 0x7f, 0xff, 0xe0, 0x7f, 0xe0, 
	0x00, 0x7f, 0xff, 0xf0, 0x7f, 0xfc, 0x01, 0xff, 0xff, 0xf0, 0x3f, 0xff, 0xff, 0xff, 0xff, 0xf0, 
	0x3f, 0xff, 0xff, 0xff, 0xff, 0xf0, 0x3f, 0xff, 0xff, 0xff, 0xff, 0xf0, 0x3f, 0xff, 0xff, 0xff, 
	0xff, 0xf0, 0x1f, 0xff, 0xff, 0xff, 0xff, 0xe0, 0x0f, 0xff, 0xff, 0xff, 0xff, 0xc0, 0x03, 0xff, 
	0xff, 0xff, 0xff, 0x80, 0x01, 0xff, 0xff, 0xff, 0xfe, 0x00, 0x00, 0x1f, 0xff, 0xff, 0xe0, 0x00, 
	0x00, 0x01, 0xff, 0xfe, 0x00, 0x00, 0x00, 0x00, 0x00, 0x00, 0x00, 0x00, 0x00, 0x00, 0x00, 0x00, 
	0x00, 0x00, 0x00, 0x00, 0x00, 0x00, 0x00, 0x00, 0x00, 0x00, 0x00, 0x00, 0x00, 0x00, 0x00, 0x00, 
	0x00, 0x00, 0x00, 0x00
};
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
void loop() {
  unsigned long now = millis();

  // === Handle button input ===
  bool reading = digitalRead(PIN_BUTTON);
  if (reading != lastButtonReading) lastDebounceTime = now;

  if ((now - lastDebounceTime) > debounceDelay) {
    if (reading != buttonState) {
      buttonState = reading;
      if (buttonState == LOW) {
        buttonPressedAt = now;
        longPressFired = false;
      } else {
        if (!longPressFired) {
          String packet = "TRIGGER_" + unitName + "_" + guid;
          if (isMaster) broadcastMessage(packet);
          else busSend(packet);
          handleMessage(packet);
          Serial.println(packet);
        }
      }
    }
    if (buttonState == LOW && !longPressFired && now - buttonPressedAt >= LONG_PRESS_MS) {
      longPressFired = true;
      handleMessage("TRIGGER_" + unitName + "_" + guid);
      Serial.println("Long press: self-only");
    }
  }
  lastButtonReading = reading;

  // === Receive from Wi-Fi ===
  if (wifiActive) {
    int packetSize = udp.parsePacket();
    if (packetSize) {
      char incoming[256];
      int len = udp.read(incoming, 255);
      if (len > 0) incoming[len] = 0;
      handleMessage(String(incoming));
    }
  }

  // === USB serial commands ===
  if (Serial.available()) {
    String cmd = Serial.readStringUntil('\n');
    cmd.trim();
    if (cmd.startsWith("name=")) {
      String newName = cmd.substring(5);
      newName.trim();
      if (newName.length() > 0 && newName.length() <= 12) {
        unitName = newName;
        prefs.begin("quickkey", false);
        prefs.putString("name", unitName);
        prefs.end();
        Serial.println("Name set: " + unitName);
      }
    }
  }

  // === Receive from Serial bus ===
  while (Serial1.available()) {
    String msg = Serial1.readStringUntil('\n');
    msg.trim();
    if (msg.length() > 0) {
      handleMessage(msg);
    }
  }

  // === Periodic slave announce ===
  if (!isMaster && now - lastSlaveAnnounce > slaveAnnounceInterval) {
    lastSlaveAnnounce = now;
    busSend("SLAVE_CONNECTED_" + unitName + "_" + guid);
  }

  // === Prune stale slaves ===
  if (isMaster) {
    for (int i = 0; i < slaveCount; i++) {
      if (now - slaves[i].lastSeen > SLAVE_TIMEOUT) {
        Serial.println("Slave lost: " + slaves[i].name);
        slaves[i] = slaves[--slaveCount];
        i--;
      }
    }
  }

  // === Master loss detection ===
  if (!isMaster && digitalRead(PIN_FLAG) == LOW) {
    unsigned long lostTime = millis();
    while (digitalRead(PIN_FLAG) == LOW && millis() - lostTime < 2000);
    if (digitalRead(PIN_FLAG) == LOW) {
      uint32_t backoff = strtoul(guid.substring(0, 8).c_str(), nullptr, 16) % 500;
      delay(backoff);
      if (digitalRead(PIN_FLAG) == LOW) {
        Serial.println("⚡ Master lost, promoting self");
        pinMode(PIN_FLAG, OUTPUT);
        digitalWrite(PIN_FLAG, HIGH);
        isMaster = true;
      }
    }
  }

  // === Animation state machine ===
  int frameInterval = (animState == COMBO) ? COMBO_FRAME_DELAY :
                      (animState == TRIGGERED) ? TRIGGERED_FRAME_DELAY : IDLE_FRAME_DELAY;

  if (now - lastFrameTime >= (unsigned long)frameInterval) {
    lastFrameTime = now;
    renderDisplay(currentFrame);

    if (animState == IDLE) {
      if (!animationReverse) {
        currentFrame++;
        if (currentFrame >= frameCount - 1) { currentFrame = frameCount - 1; animationReverse = true; }
      } else {
        currentFrame--;
        if (currentFrame <= 0) { currentFrame = 0; animationReverse = false; }
      }
    } else {
      currentFrame = (currentFrame + 1) % frameCount;
      unsigned long elapsed = now - stateStartTime;
      unsigned long duration = (animState == COMBO) ? COMBO_DURATION : TRIGGERED_DURATION;
      if (elapsed >= duration) enterState(IDLE, "");
    }
  }
}

// === Render frame with overlay ===
void renderDisplay(int frameIndex) {
  bool hasOverlay = overlayText.length() > 0;
  int yOffset = hasOverlay ? 16 : 9;

  display.clearDisplay();
  display.drawBitmap(
    (SCREEN_WIDTH - 46) / 2,
    (SCREEN_HEIGHT - 46) / 2 + yOffset,
    frames[frameIndex],
    46, 46, SSD1306_WHITE
  );

  if (hasOverlay) {
    display.setTextSize(1);
    display.setTextColor(SSD1306_WHITE);
    display.setCursor((SCREEN_WIDTH - overlayText.length() * 6) / 2, 1);
    display.print(overlayText);
  }

  if (isMaster && slaveCount > 0) {
    display.setTextSize(1);
    display.setTextColor(SSD1306_WHITE);
    display.setCursor(0, 0);
    display.print(slaveCount);
  }

  display.display();
}

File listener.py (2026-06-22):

import os
import subprocess
import serial
import socket
import threading
import time
from datetime import datetime

SCRIPT_DIR = os.path.dirname(os.path.abspath(__file__))

# === Config ===
SERIAL_PORT  = "/dev/tty.usbmodem14601"
BAUD         = 115200
UDP_PORT     = 5555
DEDUP_WINDOW = 0.5

# === Per-unit trigger handlers ===
# Return True to suppress the default log line.
# Stubs — replace body to handle events. Signature: (unit_name, guid, source) -> bool
# Return True to suppress the default log line.
def on_trigger(*_) -> bool:
    return False

TRIGGER_HANDLERS: dict[str, callable] = {
    # "ButtonA": lambda guid, source: subprocess.run(["osascript", "-e", '...']),
}

# Signature: (unit_names: list[str], source: str) -> bool
def on_combo(*_) -> bool:
    return False

# Signature: (unit_name: str, guid: str) -> bool
def on_slave_connected(*_) -> bool:
    return False

# === State ===
_dedup: dict[str, float] = {}
_dedup_lock = threading.Lock()
_slaves: dict[str, str] = {}   # guid -> name

def _ts() -> str:
    return datetime.now().strftime("%H:%M:%S")

def _dedup_check(key: str) -> bool:
    """Returns True if the message is a duplicate and should be dropped."""
    now = time.monotonic()
    with _dedup_lock:
        if now - _dedup.get(key, 0) < DEDUP_WINDOW:
            return True
        _dedup[key] = now
        expired = [k for k, v in _dedup.items() if now - v > DEDUP_WINDOW * 20]
        for k in expired:
            del _dedup[k]
    return False

def _handle_trigger(parts: list[str], source: str):
    if len(parts) < 3:
        return
    unit_name = parts[1]
    guid      = parts[2]

    if _dedup_check(f"TRIGGER_{guid}"):
        return

    handler = TRIGGER_HANDLERS.get(unit_name)
    if handler:
        handler(guid, source)
    else:
        subprocess.Popen(["python", "main.py"], cwd=SCRIPT_DIR)
        if not on_trigger(unit_name, guid, source):
            print(f"[{_ts()}][{source}] TRIGGER  unit={unit_name}  id={guid[-4:]}")

def _handle_combo(source: str):
    key = f"COMBO_{int(time.monotonic() / DEDUP_WINDOW)}"
    if _dedup_check(key):
        return
    names = list(_slaves.values()) if _slaves else []
    if not on_combo(names, source):
        print(f"[{_ts()}][{source}] COMBO!   units={names if names else '?'}")

def _handle_slave_connected(parts: list[str], source: str):
    if len(parts) < 3:
        return
    # Format: SLAVE_CONNECTED_<name>_<guid>
    unit_name  = parts[1]
    slave_guid = parts[2]
    _slaves[slave_guid] = unit_name
    if not on_slave_connected(unit_name, slave_guid):
        print(f"[{_ts()}][{source}] ONLINE   unit={unit_name}  id={slave_guid[-4:]}")

_DISPATCH = {
    "TRIGGER": _handle_trigger,
    "COMBO":   lambda _, source: _handle_combo(source),
    "SLAVE":   _handle_slave_connected,
}

def handle_message(raw: str, source: str):
    parts = raw.strip().split("_")
    if not parts:
        return
    handler = _DISPATCH.get(parts[0])
    if handler:
        handler(parts, source)
    else:
        print(f"[{_ts()}][{source}] {raw}")

# === Transport threads ===
def serial_listener():
    while True:
        try:
            ser = serial.Serial(SERIAL_PORT, BAUD, timeout=1)
            print(f"[{_ts()}] Serial connected on {SERIAL_PORT}")
            while True:
                line = ser.readline().decode(errors="ignore").strip()
                if line:
                    handle_message(line, "USB")
        except serial.SerialException:
            print(f"[{_ts()}] Serial port {SERIAL_PORT} not found — UDP still active, retrying in 5s")
            time.sleep(5)

def udp_listener():
    sock = socket.socket(socket.AF_INET, socket.SOCK_DGRAM)
    if os.name != "nt":
        sock.setsockopt(socket.SOL_SOCKET, socket.SO_REUSEADDR, 1)
    try:
        sock.bind(("", UDP_PORT))
    except OSError as e:
        print(f"[{_ts()}] UDP bind failed on port {UDP_PORT}: {e}")
        print(f"[{_ts()}] Check nothing else is using port {UDP_PORT}, or allow it through your firewall.")
        return
    print(f"[{_ts()}] UDP listening on port {UDP_PORT}")
    while True:
        data, addr = sock.recvfrom(1024)
        msg = data.decode(errors="ignore").strip()
        handle_message(msg, f"WiFi/{addr[0]}")

if __name__ == "__main__":
    print(f"Quickkey listener  —  serial={SERIAL_PORT}  udp={UDP_PORT}\n")
    threading.Thread(target=serial_listener, daemon=True).start()
    threading.Thread(target=udp_listener,    daemon=True).start()
    try:
        while True:
            time.sleep(0.1)
    except KeyboardInterrupt:
        print("\nExiting.")

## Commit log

2026-06-06 init commit
    [Quickkeys- bottom.stl, Quickkeys-newtop.stl]
2026-06-21 Update quickkey.ino
    boilerplate wifi config template replacement
    [quickkey.ino]
